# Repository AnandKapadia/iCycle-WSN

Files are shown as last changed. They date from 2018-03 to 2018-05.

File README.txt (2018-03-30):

README: 

This repository contains all of the files and documentation for the iCycle project. 

00_Documentation
01_Hardware 
	01_00_Reference
		Sparkfun library for the ATmega128RFA1_Dev (https://github.com/sparkfun/ATmega128RFA1_Dev)
	01_01_Library
	01_02_PCB
		v0.1 with arduinio mini, not finished, needs 4 layers
		v0.2 completed board with xbee, buzzer, leds
02_Software 
	01_00_Reference
		Sparkfun library for the ATmega128RFA1_Dev (https://github.com/sparkfun/ATmega128RFA1_Dev)

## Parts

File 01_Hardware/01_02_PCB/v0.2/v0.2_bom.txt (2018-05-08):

Partlist exported from /Users/akhome/Desktop/Year 4_2/18748/iCycle-WSN/01_Hardware/01_02_PCB/v0.2/v0.2.sch at 4/16/18 10:23 AM

Qty Value         Device               Package           Parts                                                                                 Description                                                                         PROD_ID     SF_SKU    VALUE     

1   16MHz         CRYSTAL5X3           CRYSTAL-SMD-5X3   MICROCONTROLLER1:Y1                                                                   Various standard crystals. Proven footprints. Spark Fun Electronics SKU : COM-00534                                 
1   32.768kHz     CRYSTAL32-SMD        CRYSTAL-32KHZ-SMD MICROCONTROLLER1:Y2                                                                   Various standard crystals. Proven footprints. Spark Fun Electronics SKU : COM-00534

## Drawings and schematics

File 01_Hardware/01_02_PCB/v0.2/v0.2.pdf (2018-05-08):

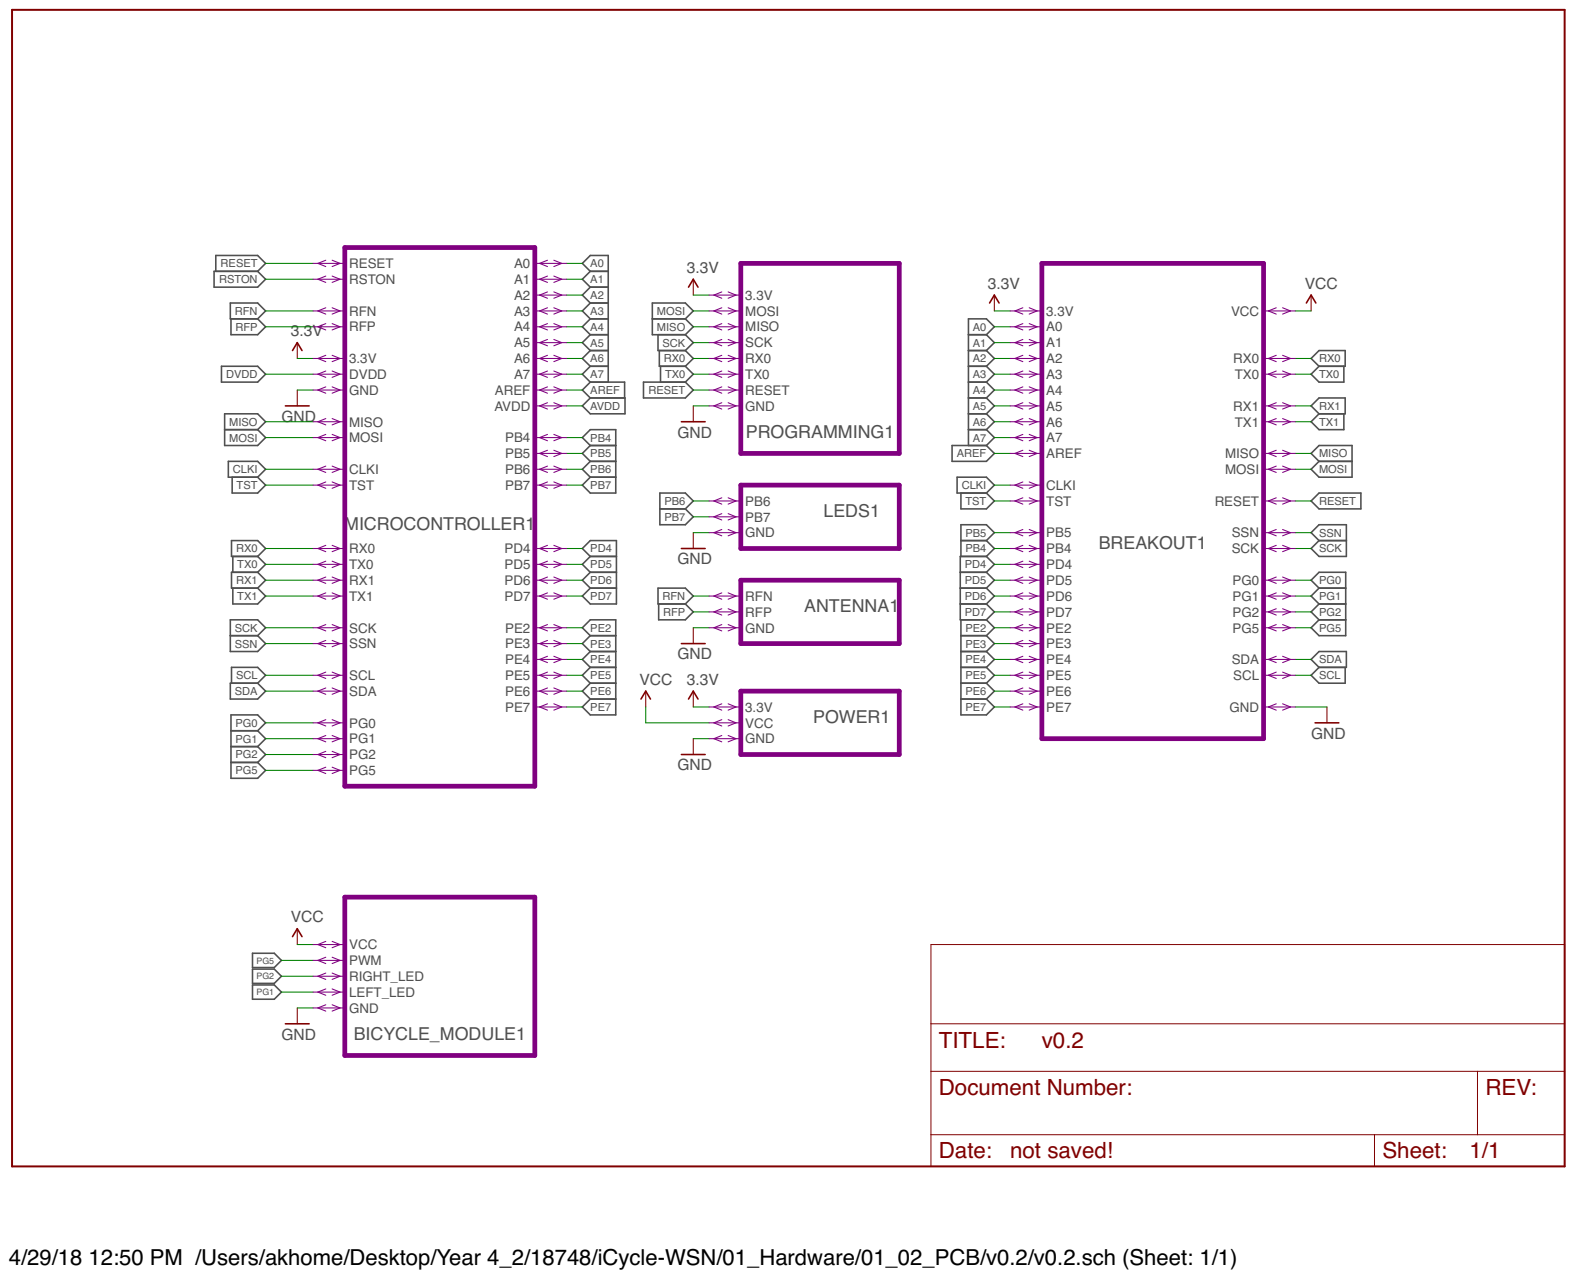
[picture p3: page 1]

RESET RFN
RSTON
RFP DVDD GND
3.3V MISO MOSI CLKI TST RX0 TX0 RX1 TX1 SCK

RESET SCK MISO MOSI RX0

Document Number: | REV:

Date: not saved! | Sheet: 1/1

4/29/18 12:50 PM /Users/akhome/Desktop/Year 4_2/18748/iCycle-WSN/01_Hardware/01_02_PCB/v0.2/v0.2.sch (Sheet: 1/1)

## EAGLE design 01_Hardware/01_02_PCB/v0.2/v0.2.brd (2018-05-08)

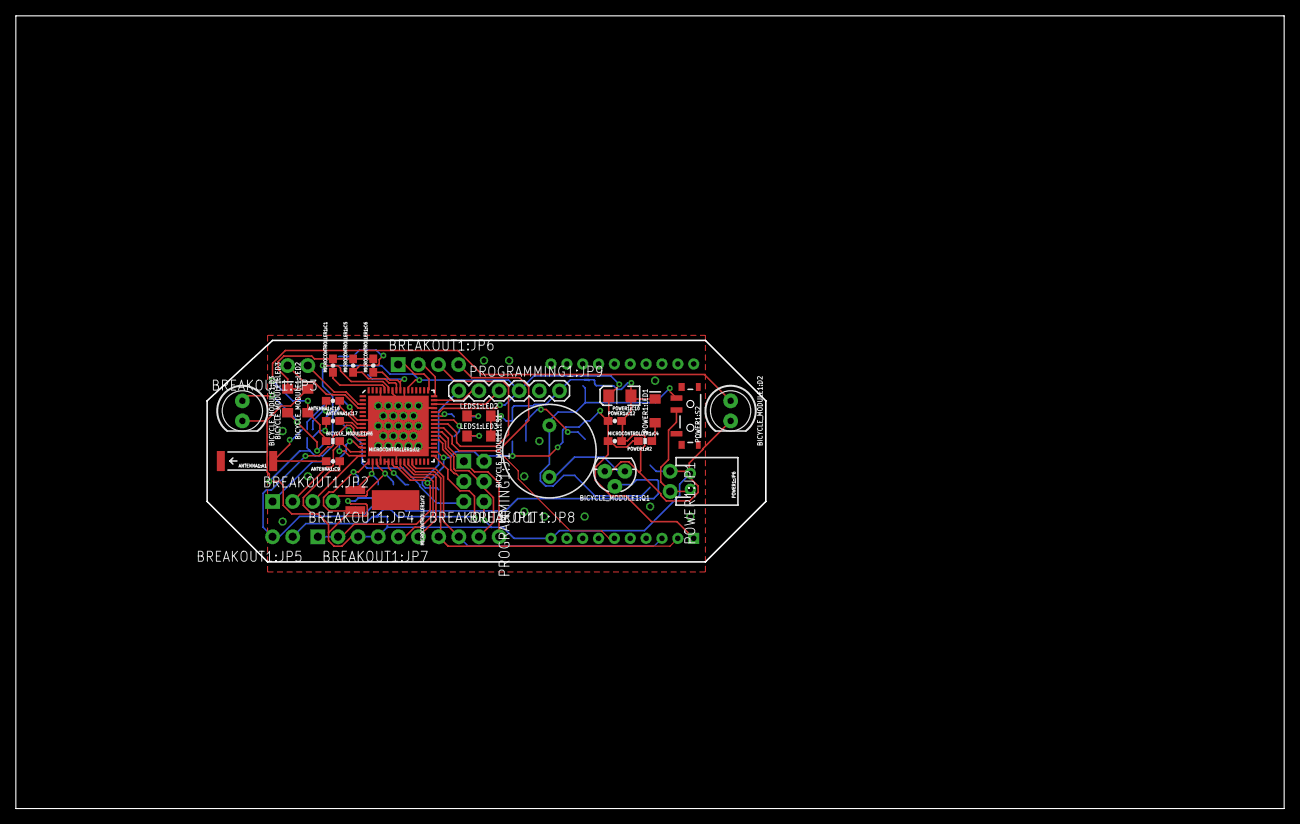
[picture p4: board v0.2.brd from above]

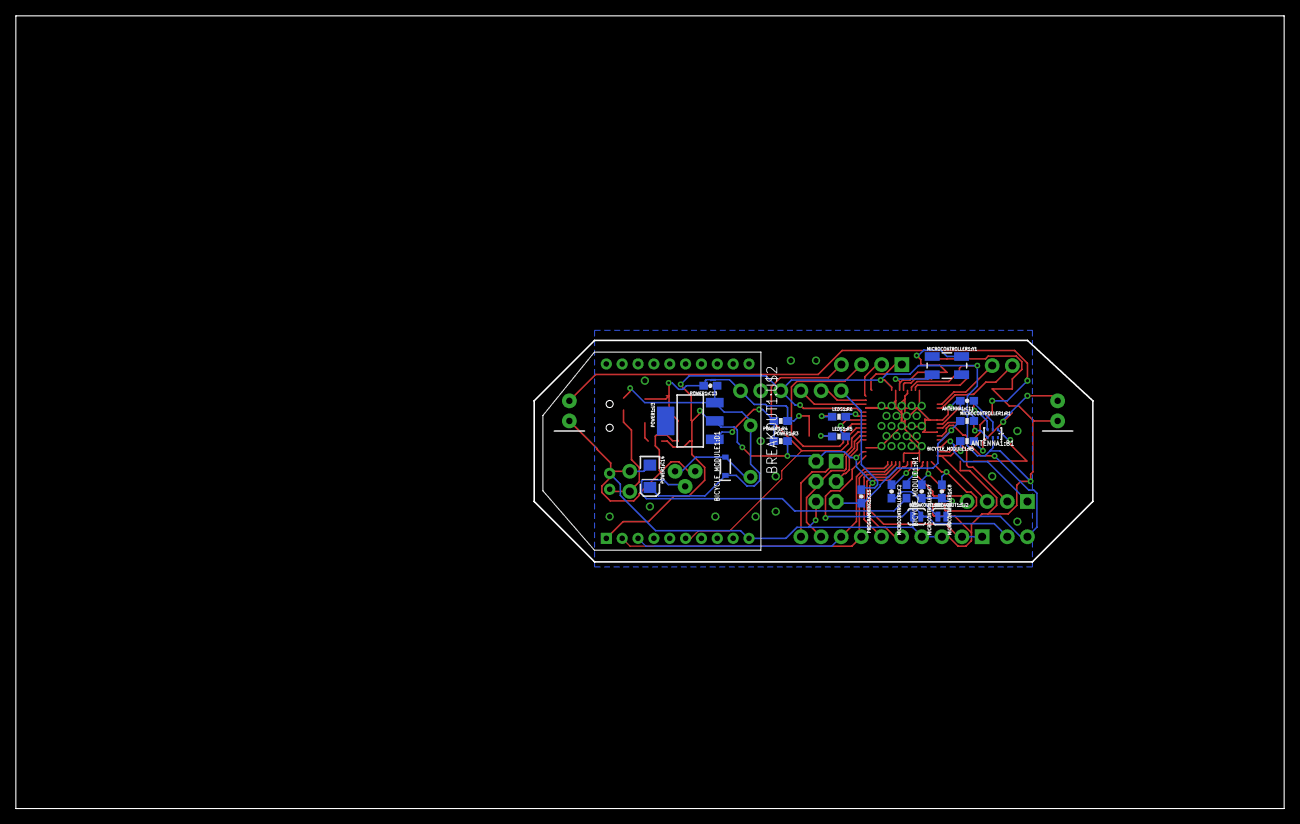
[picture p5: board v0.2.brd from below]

Board: 2 copper layers, 160.0 x 100.0 mm, 57 parts (21 on the bottom side), 49 nets.

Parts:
ANTENNA1:A1: ANTENNA2SMD5; ANTENNA-CHIP5
ANTENNA1:B1: 748421245; BALUN-0805
ANTENNA1:C9: 0.75pF; 0603-CAP
ANTENNA1:C11: 22pF; 0603-CAP
ANTENNA1:C16, ANTENNA1:C17: JUMP; 0603-CAP
BICYCLE_MODULE1:D1: 250mA/100V; SOD-323
BICYCLE_MODULE1:D2, BICYCLE_MODULE1:D3: LED_5MM
BICYCLE_MODULE1:LED2, BICYCLE_MODULE1:LED3: GREEN; LED-1206
BICYCLE_MODULE1:LS1: BUZZER-PTH; BUZZER-12MM
BICYCLE_MODULE1:Q1: 600mA/40V; TO-92
BICYCLE_MODULE1:R1: 180; 0603
BICYCLE_MODULE1:R5, BICYCLE_MODULE1:R6: 330; 0603-RES
BREAKOUT1:JP1, BREAKOUT1:JP3, BREAKOUT1:JP5, BREAKOUT1:JP7, BREAKOUT1:JP8: 1X02_NO_SILK
BREAKOUT1:JP2, BREAKOUT1:JP4, BREAKOUT1:JP6: 1X04_NO_SILK
BREAKOUT1:SJ1, BREAKOUT1:SJ2: SJ_2S-TRACE
BREAKOUT1:U$2: XBEE
LEDS1:LED2, LEDS1:LED3: GREEN; LED-1206
LEDS1:R5, LEDS1:R6: 330; 0603-RES
MICROCONTROLLER1:C1, MICROCONTROLLER1:C2, MICROCONTROLLER1:C4: 1uF; 0603-CAP
MICROCONTROLLER1:C5, MICROCONTROLLER1:C6, MICROCONTROLLER1:C7, MICROCONTROLLER1:C8: 12pF; 0603-CAP
MICROCONTROLLER1:R1: 10k; 0603-RES
MICROCONTROLLER1:U2: ATMEGA128RFA1; QFN-64
MICROCONTROLLER1:Y1: 16MHz; CRYSTAL-SMD-5X3
MICROCONTROLLER1:Y2: 32.768kHz; CRYSTAL-32KHZ-SMD
POWER1:C10, POWER1:C14: 10uF; EIA3216
POWER1:C12: 1uF; 0603-CAP
POWER1:C13: 0.1uF; 0603-CAP
POWER1:JP1: 1X02_NO_SILK
POWER1:JP6: JST-2-PTH
POWER1:LED1: RED; LED-1206
POWER1:R2: 1k; 0603-RES
POWER1:R3: 240; 0603-RES
POWER1:R4: 390; 0603-RES
POWER1:S2: SWITCH-SPST-SMD-A
POWER1:U3: LM1117; SOT223
PROGRAMMING1:C15: 0.1uF; 0603-CAP
PROGRAMMING1:J1: ISP; 2X3-NS
PROGRAMMING1:JP9: FTDI; FTDI_BASIC

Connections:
3.3V: BREAKOUT1:JP4.1, BREAKOUT1:JP4.2, BREAKOUT1:U$2.1, MICROCONTROLLER1:C4.1, MICROCONTROLLER1:R1.2, MICROCONTROLLER1:U2.23, MICROCONTROLLER1:U2.34, MICROCONTROLLER1:U2.44, MICROCONTROLLER1:U2.54, MICROCONTROLLER1:U2.59, POWER1:C10.A, POWER1:C12.1, POWER1:R2.2, POWER1:R3.2, POWER1:U3.2, PROGRAMMING1:J1.2, PROGRAMMING1:JP9.VCC
A4: BREAKOUT1:JP3.1, MICROCONTROLLER1:U2.3
A5: BREAKOUT1:JP3.2, MICROCONTROLLER1:U2.4
ANTENNA1:N$62: ANTENNA1:B1.2, ANTENNA1:C11.1
ANTENNA1:N$63: ANTENNA1:B1.3, ANTENNA1:C16.2
ANTENNA1:N$64: ANTENNA1:B1.4, ANTENNA1:C17.1
ANTENNA1:RFANT: ANTENNA1:A1.FEED, ANTENNA1:B1.1, ANTENNA1:C9.2
AVDD: MICROCONTROLLER1:C1.1, MICROCONTROLLER1:U2.60
BICYCLE_MODULE1:N$1: BICYCLE_MODULE1:Q1.2, BICYCLE_MODULE1:R1.2
BICYCLE_MODULE1:N$2: BICYCLE_MODULE1:D1.A, BICYCLE_MODULE1:LS1.-, BICYCLE_MODULE1:Q1.1
BICYCLE_MODULE1:N$65: BICYCLE_MODULE1:D3.A, BICYCLE_MODULE1:LED3.A, BICYCLE_MODULE1:R5.1
BICYCLE_MODULE1:N$66: BICYCLE_MODULE1:D2.A, BICYCLE_MODULE1:LED2.A, BICYCLE_MODULE1:R6.1
CLKI: BREAKOUT1:JP5.1, BREAKOUT1:SJ1.2, MICROCONTROLLER1:U2.33
DVDD: MICROCONTROLLER1:C2.1, MICROCONTROLLER1:U2.21, MICROCONTROLLER1:U2.22
GND: ANTENNA1:B1.5, ANTENNA1:C9.1, ANTENNA1:C11.2, BICYCLE_MODULE1:D2.K, BICYCLE_MODULE1:D3.K, BICYCLE_MODULE1:LED2.C, BICYCLE_MODULE1:LED3.C, BICYCLE_MODULE1:Q1.3, BREAKOUT1:JP4.3, BREAKOUT1:JP4.4, BREAKOUT1:SJ1.1, BREAKOUT1:SJ2.1, BREAKOUT1:U$2.10, LEDS1:LED2.C, LEDS1:LED3.C, MICROCONTROLLER1:C1.2, MICROCONTROLLER1:C2.2, MICROCONTROLLER1:C4.2, MICROCONTROLLER1:C5.2, MICROCONTROLLER1:C6.2, MICROCONTROLLER1:C7.2, MICROCONTROLLER1:C8.2, MICROCONTROLLER1:U2.7, MICROCONTROLLER1:U2.10, MICROCONTROLLER1:U2.20, MICROCONTROLLER1:U2.24, MICROCONTROLLER1:U2.35, MICROCONTROLLER1:U2.45, MICROCONTROLLER1:U2.55, MICROCONTROLLER1:U2.58, MICROCONTROLLER1:U2.61, MICROCONTROLLER1:U2.65, POWER1:C10.C, POWER1:C12.2, POWER1:C13.2, POWER1:C14.C, POWER1:JP1.1, POWER1:JP6.1, POWER1:LED1.C, POWER1:R4.1, PROGRAMMING1:J1.6, PROGRAMMING1:JP9.GND
LEDS1:N$65: LEDS1:LED3.A, LEDS1:R5.1
LEDS1:N$66: LEDS1:LED2.A, LEDS1:R6.1
MICROCONTROLLER1:N$57: MICROCONTROLLER1:C5.1, MICROCONTROLLER1:U2.57, MICROCONTROLLER1:Y1.3
MICROCONTROLLER1:N$58: MICROCONTROLLER1:C6.1, MICROCONTROLLER1:U2.56, MICROCONTROLLER1:Y1.1
MICROCONTROLLER1:N$59: MICROCONTROLLER1:C7.1, MICROCONTROLLER1:U2.18, MICROCONTROLLER1:Y2.X1
MICROCONTROLLER1:N$60: MICROCONTROLLER1:C8.1, MICROCONTROLLER1:U2.17, MICROCONTROLLER1:Y2.X2
MISO: BREAKOUT1:JP8.2, MICROCONTROLLER1:U2.39, PROGRAMMING1:J1.1
MOSI: BREAKOUT1:JP8.1, MICROCONTROLLER1:U2.38, PROGRAMMING1:J1.4
PB4: BREAKOUT1:JP6.4, BREAKOUT1:U$2.6, MICROCONTROLLER1:U2.40
PB5: BREAKOUT1:JP6.3, MICROCONTROLLER1:U2.41
PB6: LEDS1:R5.2, MICROCONTROLLER1:U2.42
PB7: LEDS1:R6.2, MICROCONTROLLER1:U2.43
PE2: BREAKOUT1:JP6.2, MICROCONTROLLER1:U2.48
PE3: BREAKOUT1:JP6.1, MICROCONTROLLER1:U2.49
PG0: BREAKOUT1:JP2.1, MICROCONTROLLER1:U2.14
PG1: BICYCLE_MODULE1:R6.2, BREAKOUT1:JP2.2, MICROCONTROLLER1:U2.15
PG2: BICYCLE_MODULE1:R5.2, BREAKOUT1:JP2.3, MICROCONTROLLER1:U2.16
PG5: BICYCLE_MODULE1:R1.1, BREAKOUT1:JP2.4, MICROCONTROLLER1:U2.19
POWER1:FB: POWER1:R3.1, POWER1:R4.2, POWER1:U3.1
POWER1:N$61: POWER1:LED1.A, POWER1:R2.1
POWER1:N$67: POWER1:JP1.2, POWER1:JP6.2, POWER1:S2.2
PROGRAMMING1:DTR: PROGRAMMING1:C15.1, PROGRAMMING1:JP9.DTR
RESET: MICROCONTROLLER1:R1.1, MICROCONTROLLER1:U2.12, PROGRAMMING1:C15.2, PROGRAMMING1:J1.5
RFN: ANTENNA1:C17.2, MICROCONTROLLER1:U2.9
RFP: ANTENNA1:C16.1, MICROCONTROLLER1:U2.8
RX0: MICROCONTROLLER1:U2.46, PROGRAMMING1:JP9.TXO
RX1: BREAKOUT1:JP1.1, BREAKOUT1:U$2.2, MICROCONTROLLER1:U2.27
SCK: MICROCONTROLLER1:U2.37, PROGRAMMING1:J1.3
SCL: BREAKOUT1:JP7.2, MICROCONTROLLER1:U2.25
SDA: BREAKOUT1:JP7.1, MICROCONTROLLER1:U2.26
TST: BREAKOUT1:JP5.2, BREAKOUT1:SJ2.2, MICROCONTROLLER1:U2.11
TX0: MICROCONTROLLER1:U2.47, PROGRAMMING1:JP9.RXI
TX1: BREAKOUT1:JP1.2, BREAKOUT1:U$2.3, MICROCONTROLLER1:U2.28
VCC: BICYCLE_MODULE1:D1.C, BICYCLE_MODULE1:LS1.+, POWER1:C13.1, POWER1:C14.A, POWER1:S2.1, POWER1:U3.3

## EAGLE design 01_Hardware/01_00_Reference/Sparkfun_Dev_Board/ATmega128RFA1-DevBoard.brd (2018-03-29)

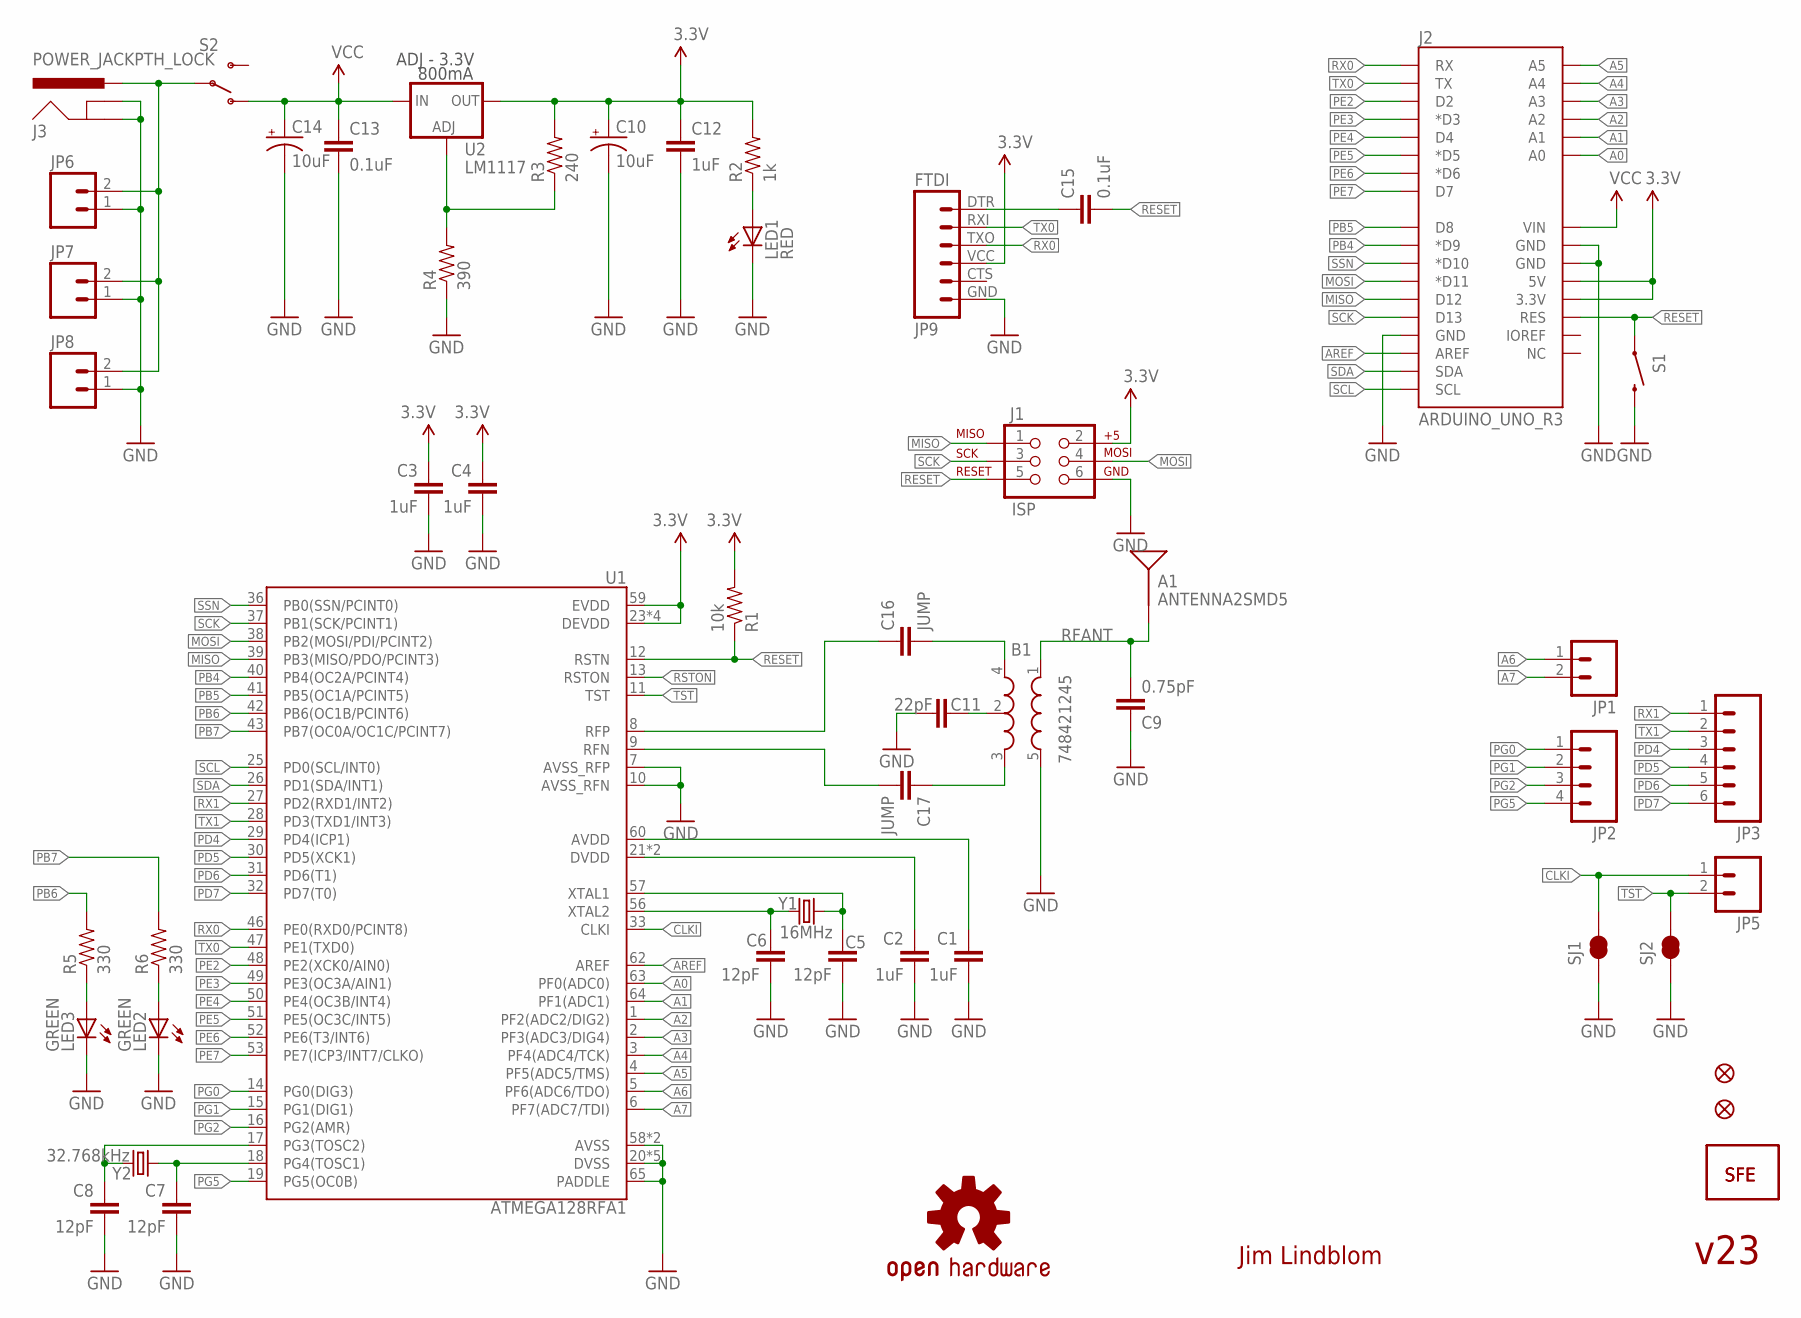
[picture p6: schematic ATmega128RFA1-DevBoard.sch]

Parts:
A1: ANTENNA2SMD5; ANTENNA-CHIP5
B1: 748421245; BALUN
C1, C2, C3, C4, C12: 1uF; 0402-CAP
C5, C6, C7, C8: 12pF; 0402-CAP
C9: 0.75pF; 0402-CAP
C10, C14: 10uF; EIA3216
C11: 22pF; 0402-CAP
C13, C15: 0.1uF; 0402-CAP
C16, C17: JUMP; 0402-CAP
FID1, FID2: FIDUCIALUFIDUCIAL; MICRO-FIDUCIAL
J1: ISP; 2X3-NS
J2: ARDUINO_UNO_R3
J3: POWER_JACKPTH_LOCK; POWER_JACK_PTH_LOCK
JP1, JP5, JP7: M021X02_NO_SILK; 1X02_NO_SILK
JP2: M041X04_NO_SILK; 1X04_NO_SILK
JP3: M06SIP-NS; 1X06_NS
JP4, JP10: LOGO-SFENEW; SFE-NEW-WEBLOGO
JP6: M02JST-PTH-2; JST-2-PTH
JP8: M023.5MM-NO_SILK; SCREWTERMINAL-3.5MM-2-NS
JP9: FTDI; FTDI_BASIC
LED1: RED; LED-0603
LED2, LED3: GREEN; LED-0603
R1: 10k; 0402-RES
R2: 1k; 0402-RES
R3: 240; 0402-RES
R4: 390; 0402-RES
R5, R6: 330; 0402-RES
S1: SWITCH-MOMENTARY-2SMD; TACTILE_SWITCH_SMD
S2: SWITCH-SPST-SMD-A
SJ1, SJ2: SOLDERJUMPERTRACE; SJ_2S-TRACE
U1: ATMEGA128RFA1; QFN-64
U2: LM1117; SOT223
U$1: OSHW-LOGOS; OSHW-LOGO-S
Y1: 16MHz; CRYSTAL-SMD-5X3
Y2: 32.768kHz; CRYSTAL-32KHZ-SMD

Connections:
3.3V: C3.1, C4.1, C10.A (+), C12.1, J1.2, J2.3.3V, J2.5V, JP9.VCC (4), R1.2, R2.2, R3.2, U1.23 (DEVDD), U1.34 (DEVDD), U1.44 (DEVDD), U1.54 (DEVDD), U1.59 (EVDD), U2.2 (OUT)
A0: J2.A0, U1.63 (PF0(ADC0))
A1: J2.A1, U1.64 (PF1(ADC1))
A2: J2.A2, U1.1 (PF2(ADC2/DIG2))
A3: J2.A3, U1.2 (PF3(ADC3/DIG4))
A4: J2.A4, U1.3 (PF4(ADC4/TCK))
A5: J2.A5, U1.4 (PF5(ADC5/TMS))
A6: JP1.1, U1.5 (PF6(ADC6/TDO))
A7: JP1.2, U1.6 (PF7(ADC7/TDI))
AREF: J2.AREF, U1.62 (AREF)
AVDD: C1.1, U1.60 (AVDD)
CLKI: JP5.1, SJ1.2, U1.33 (CLKI)
DTR: C15.1, JP9.DTR (1)
DVDD: C2.1, U1.21 (DVDD), U1.22 (DVDD)
FB: R3.1, R4.2, U2.1 (ADJ)
GND: B1.5 (GND), C1.2, C2.2, C3.2, C4.2, C5.2, C6.2, C7.2, C8.2, C9.1, C10.C (-), C11.2, C12.2, C13.2, C14.C (-), J1.6, J2.GND@0 (GND), J2.GND@1 (GND), J2.GND@2 (GND), J3.GND, J3.GNDBREAK, JP6.1, JP7.1, JP8.1, JP9.GND (6), LED1.C, LED2.C, LED3.C, R4.1, S1.3 (2), SJ1.1, SJ2.1, U1.7 (AVSS_RFP), U1.10 (AVSS_RFN), U1.20 (DVSS), U1.24 (DVSS), U1.35 (DVSS), U1.45 (DVSS), U1.55 (DVSS), U1.58 (AVSS), U1.61 (AVSS), U1.65 (PADDLE)
MISO: J1.1, J2.D12, U1.39 (PB3(MISO/PDO/PCINT3))
MOSI: J1.4, J2.D11 (*D11), U1.38 (PB2(MOSI/PDI/PCINT2))
unnamed: LED1.A, R2.1
unnamed: C5.1, U1.57 (XTAL1), Y1.3 (2)
unnamed: C6.1, U1.56 (XTAL2), Y1.1
unnamed: C7.1, U1.18 (PG4(TOSC1)), Y2.X1 (1)
unnamed: C8.1, U1.17 (PG3(TOSC2)), Y2.X2 (2)
unnamed: B1.2 (GND), C11.1
unnamed: LED3.A, R5.1
unnamed: J3.PWR, JP6.2, JP7.2, JP8.2, S2.2
unnamed: B1.4 (OUT1), C16.2
unnamed: B1.3 (OUT2), C17.1
unnamed: LED2.A, R6.1
PB4: J2.D9 (*D9), U1.40 (PB4(OC2A/PCINT4))
PB5: J2.D8, U1.41 (PB5(OC1A/PCINT5))
PB6: R5.2, U1.42 (PB6(OC1B/PCINT6))
PB7: R6.2, U1.43 (PB7(OC0A/OC1C/PCINT7))
PD4: JP3.3, U1.29 (PD4(ICP1))
PD5: JP3.4, U1.30 (PD5(XCK1))
PD6: JP3.5, U1.31 (PD6(T1))
PD7: JP3.6, U1.32 (PD7(T0))
PE2: J2.D2, U1.48 (PE2(XCK0/AIN0))
PE3: J2.D3 (*D3), U1.49 (PE3(OC3A/AIN1))
PE4: J2.D4, U1.50 (PE4(OC3B/INT4))
PE5: J2.D5 (*D5), U1.51 (PE5(OC3C/INT5))
PE6: J2.D6 (*D6), U1.52 (PE6(T3/INT6))
PE7: J2.D7, U1.53 (PE7(ICP3/INT7/CLKO))
PG0: JP2.1, U1.14 (PG0(DIG3))
PG1: JP2.2, U1.15 (PG1(DIG1))
PG2: JP2.3, U1.16 (PG2(AMR))
PG5: JP2.4, U1.19 (PG5(OC0B))
RESET: C15.2, J1.5, J2.RES, R1.1, S1.1, U1.12 (RSTN)
RFANT: A1.FEED, B1.1 (IN), C9.2
RFN: C17.2, U1.9 (RFN)
RFP: C16.1, U1.8 (RFP)
RSTON: U1.13 (RSTON)
RX0: J2.RX, JP9.TXO (3), U1.46 (PE0(RXD0/PCINT8))
RX1: JP3.1, U1.27 (PD2(RXD1/INT2))
SCK: J1.3, J2.D13, U1.37 (PB1(SCK/PCINT1))
SCL: J2.SCL, U1.25 (PD0(SCL/INT0))
SDA: J2.SDA, U1.26 (PD1(SDA/INT1))
SSN: J2.D10 (*D10), U1.36 (PB0(SSN/PCINT0))
TST: JP5.2, SJ2.2, U1.11 (TST)
TX0: J2.TX, JP9.RXI (2), U1.47 (PE1(TXD0))
TX1: JP3.2, U1.28 (PD3(TXD1/INT3))
VCC: C13.1, C14.A (+), J2.VIN, S2.1 (O), U2.3 (IN)

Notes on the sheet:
Jim Lindblom
800mA
ADJ - 3.3V
v23

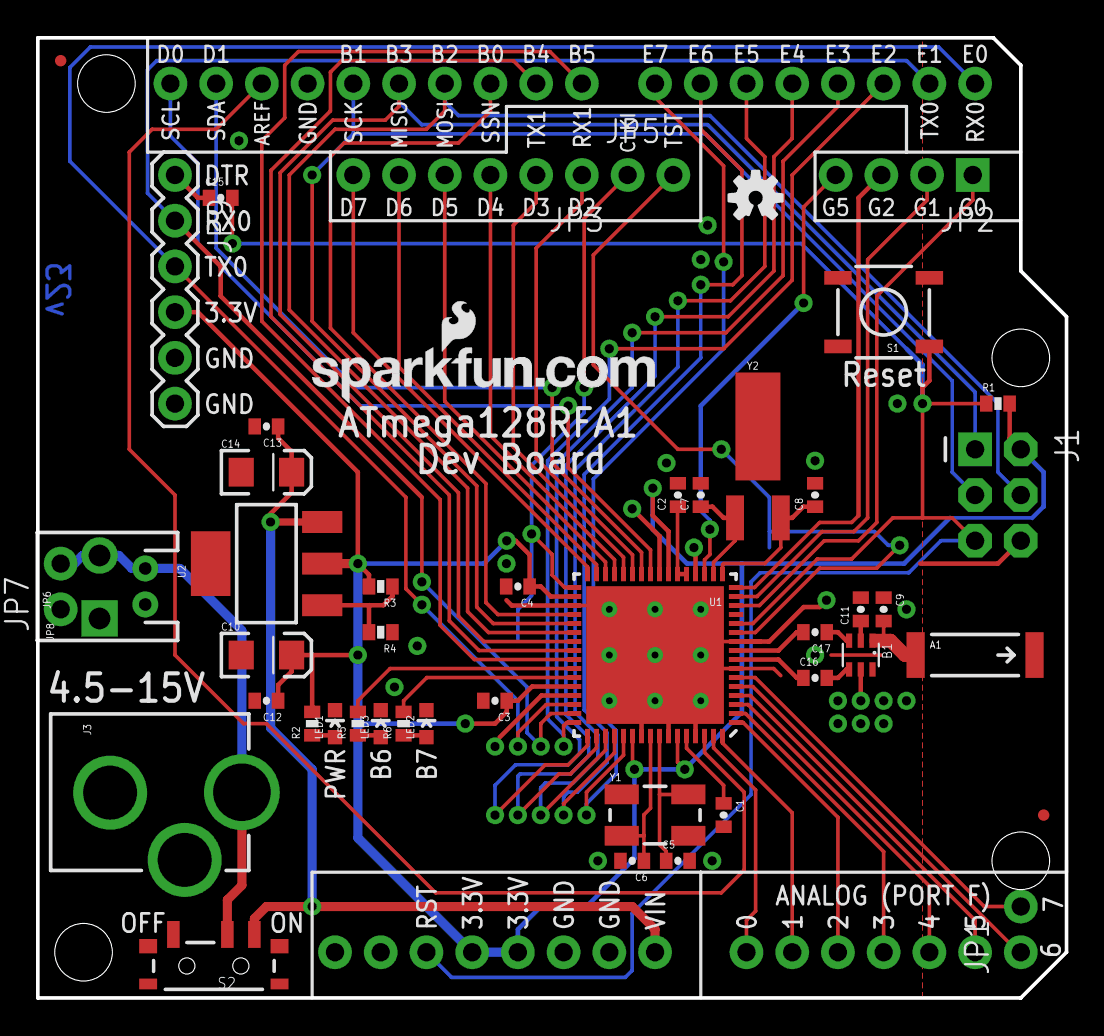
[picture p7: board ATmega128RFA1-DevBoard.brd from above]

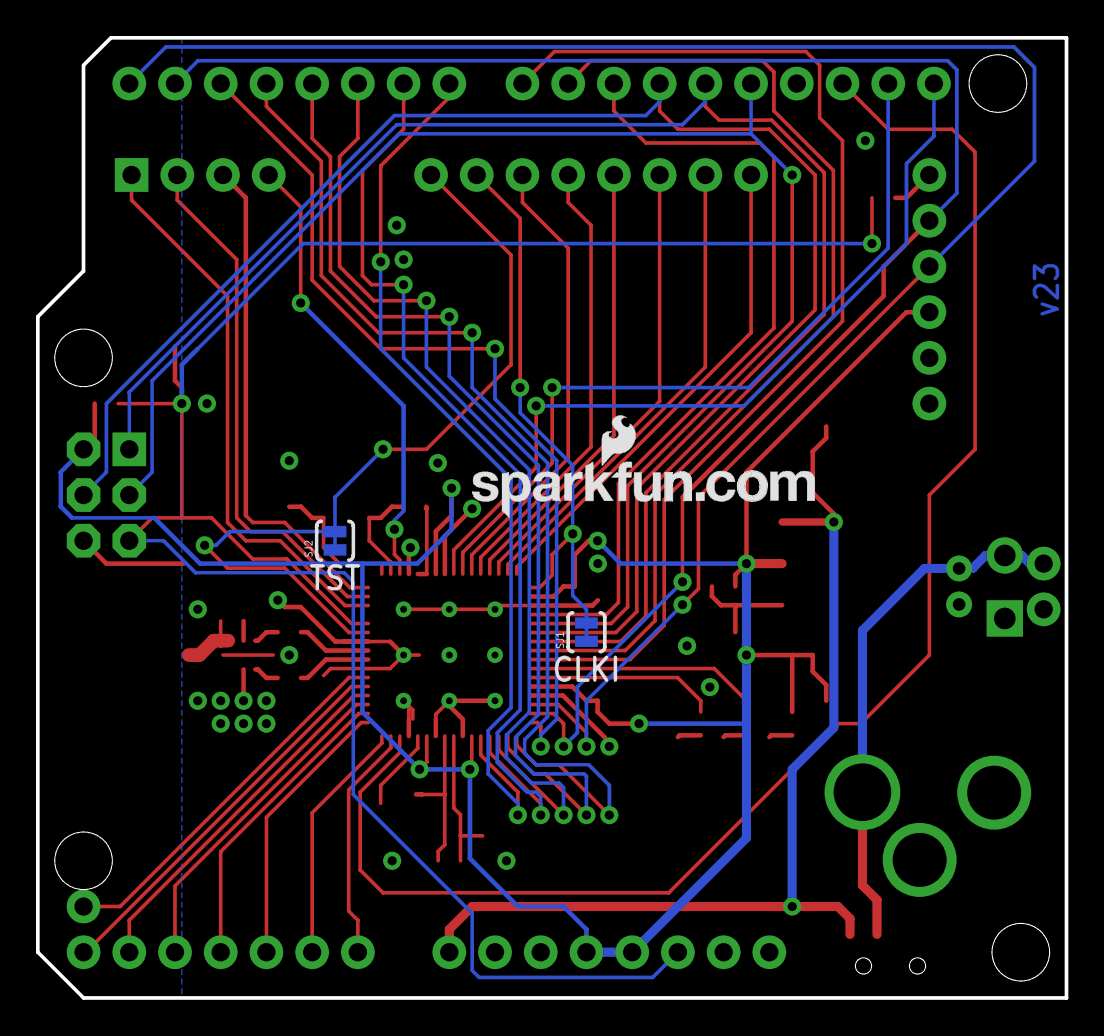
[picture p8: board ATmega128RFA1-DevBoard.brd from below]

Board: 2 copper layers, 57.1 x 53.3 mm, 52 parts (3 on the bottom side), 61 nets.

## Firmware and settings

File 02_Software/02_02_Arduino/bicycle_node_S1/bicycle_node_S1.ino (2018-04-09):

/**
 * Copyright (c) 2009 Andrew Rapp. All rights reserved.
 *
 * This file is part of XBee-Arduino.
 *
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
 * You should have received a copy of the GNU General Public License
 * along with XBee-Arduino.  If not, see <http://www.gnu.org/licenses/>.
 */

#include <XBee.h>
#include <SparkFun_ADXL345.h>

#define XBEE_SUCCESS  0
#define XBEE_ERROR    0xff
#define XBEE_RX_EMPTY 1


#define BROADCAST_ADDRESS (0xFFFF)

// create the XBee object
XBee xbee = XBee();

// create the accelerometer object (i2c)
ADXL345 accelerometer = ADXL345();           


/*
// allocate two bytes for to hold a 10-bit analog reading
uint8_t payload[] = { 0, 0 };

// with Series 1 you can use either 16-bit or 64-bit addressing

// 16-bit addressing: Enter address of remote XBee, typically the coordinator
Tx16Request tx = Tx16Request(0xFFFF, payload, sizeof(payload));

// 64-bit addressing: This is the SH + SL address of remote XBee
//XBeeAddress64 addr64 = XBeeAddress64(0x0013a200, 0x4008b490);
// unless you have MY on the receiving radio set to FFFF, this will be received as a RX16 packet
//Tx64Request tx = Tx64Request(addr64, payload, sizeof(payload));

TxStatusResponse txStatus = TxStatusResponse();
*/
// IO Pinmap

const int leftLed = 2;
const int rightLed = 4;
const int txLed = 7;
const int statusLed = 8;
const int rxLed = 9;
const int buzzer = 10;
const int buttonPin = 12;
const int errorLed = 13;

static Rx16Response rx16 = Rx16Response();

typedef struct{
  int16_t x;
  int16_t y;
  int16_t z;
} accel_data_t;

typedef enum location_field_t {
  NORTH,
  NORTHEAST,
  EAST,
  SOUTHEAST,
  SOUTH,
  SOUTHWEST,
  WEST,
  NORTHWEST
} location_field_t;

void setup() {
  //start the serial port
  Serial.begin(9600);
  
  //setup the io
  pinMode(leftLed, OUTPUT);
  pinMode(rightLed, OUTPUT);
  pinMode(txLed, OUTPUT);
  pinMode(rxLed, OUTPUT);
  pinMode(statusLed, OUTPUT);
  pinMode(errorLed, OUTPUT);
  pinMode(buzzer, OUTPUT);
  pinMode(buttonPin, INPUT);

  //ensure all leds work
  flashLed(leftLed, 2, 250);
  flashLed(rightLed, 2, 250);
  flashLed(txLed, 2, 250);
  flashLed(rxLed, 2, 250);
  flashLed(statusLed, 2, 250);
  flashLed(errorLed, 2, 250);
  flashLed(buzzer, 2, 250);

  //accel setup
  setup_accelerometer();

  //xbee setup
  xbee.setSerial(Serial);
}


void loop() {  
  //inits
  uint8_t count = 0;
  static bool buzzer_bool = false;
  static uint16_t buzzer_count = 0;
  uint8_t buttonVal = digitalRead(buttonPin);
  uint8_t txPayload[1] = {0};
  accel_data_t accel_data;
  accel_data.x = 0;
  accel_data.y = 0;
  accel_data.z = 0;

  //send if button pushed
  if(buttonVal) {
    while(buttonVal) {
      count++;
      buttonVal = digitalRead(buttonPin);
      delay(100);
    }

    //get the accelerometer data
    accelerometer.readAccel(&(accel_data.x), &(accel_data.y), &(accel_data.z)); 
    Serial.print(accel_data.x);
    Serial.print(", ");
    Serial.print(accel_data.y);
    Serial.print(", ");
    Serial.println(accel_data.z); 
    sendPacket(BROADCAST_ADDRESS, (uint8_t *)&accel_data, sizeof(accel_data_t));
    flashLed(statusLed, count, 50);
    delay(1000);
  }

  if(buzzer_bool){
    buzzer_count++;
  }
  else{
    buzzer_count = 0;
  }
  if(buzzer_count > 1000){
    buzzer_count = 0;
    buzzer_bool = false; 
    digitalWrite(buzzer, LOW);
    delay(1);
  }
  uint8_t retv;
  retv = retrievePacket();
  if(retv  == XBEE_ERROR) {
    flashLed(errorLed, 2, 100);
  } else if(retv == XBEE_SUCCESS){
    
    flashLed(rxLed, 2, 100);
    uint8_t *rxPayload = rx16.getData();
    uint8_t *rxFrame = rx16.getFrameData();
    uint16_t sourceAddr;
    location_field_t location;
    sourceAddr = (((uint16_t) rxFrame[0]) << 8) | ((uint16_t) rxFrame[1]);//*(uint16_t*)rxFrame;
    if(sourceAddr == 0){
      location = rxPayload[0];
      switch(location){
        case SOUTH: 
          digitalWrite(leftLed, LOW);
          digitalWrite(rightLed, LOW);
          digitalWrite(buzzer, LOW);
          buzzer_bool = false;
          delay(1);
          break;
        case NORTHEAST:
          digitalWrite(buzzer, HIGH);
          digitalWrite(rightLed, HIGH);
          digitalWrite(leftLed, LOW);
          buzzer_bool = true;
          break;
        case SOUTHEAST: 
        case EAST: 
          digitalWrite(rightLed, HIGH);
          digitalWrite(leftLed, LOW);          
          digitalWrite(buzzer, LOW);
          buzzer_bool = false;
          break;
        case NORTHWEST:
          digitalWrite(buzzer, HIGH);
          digitalWrite(rightLed, LOW);
          digitalWrite(leftLed, HIGH);
          buzzer_bool = true;
          break;
        case SOUTHWEST: 
        case WEST: 
          digitalWrite(rightLed, LOW);
          digitalWrite(leftLed, HIGH);          
          digitalWrite(buzzer, LOW);
          buzzer_bool = false;
          break;
        case NORTH:
          digitalWrite(leftLed, LOW);
          digitalWrite(rightLed, LOW);
          digitalWrite(buzzer, HIGH);
          buzzer_bool = true;
          break;
        default: 
          break;
      }
      delay(1);
    }
  }

 
  delay(1);
}


// Helper for sending an XBee Packet
// TODO add condition codes
void sendPacket(uint16_t destAddress, uint8_t* payload, uint8_t payloadSize) {

  // Setup the packet to send to the master node, typically the coordinator
  Tx16Request tx = Tx16Request(destAddress, payload, payloadSize);
  // Packet to hold the reponse from XBee after transmission complete
  TxStatusResponse txStatus = TxStatusResponse();

  xbee.send(tx);

  // flash TX indicator
  flashLed(txLed, 1, 100);
  
  // after sending a tx request, we expect a status response
  // wait up to 5 seconds for the status response
  if (xbee.readPacket(5000)) {
    // got a response!

    // should be a znet tx status              
    if (xbee.getResponse().getApiId() == TX_STATUS_RESPONSE) {
      xbee.getResponse().getTxStatusResponse(txStatus);

      // get the delivery status, the fifth byte
      if (txStatus.getStatus() == SUCCESS) {
        // success.  time to celebrate
        flashLed(txLed, 2, 250);
      } else {
        // the remote XBee did not receive our packet. is it powered on?
        flashLed(errorLed, 3, 250);
      }
    }      
  } else if (xbee.getResponse().isError()) {
    //nss.print("Error reading packet.  Error code: ");  
    //nss.println(xbee.getResponse().getErrorCode());
    // or flash error led
  } else {
    // local XBee did not provide a timely TX Status Response.  Radio is not configured properly or connected
    flashLed(errorLed, 2, 250);
  }
}




//Retrieve a received packet and store it in rx16
uint8_t retrievePacket(){
  xbee.readPacket();
    
  if (xbee.getResponse().isAvailable()) {
    // got something
    if (xbee.getResponse().getApiId() == RX_16_RESPONSE) {
      // got a rx packet
      xbee.getResponse().getRx64Response(rx16);
      return XBEE_SUCCESS;
    } else {
      // not something we were expecting
      return XBEE_ERROR;    
    }
  } else if (xbee.getResponse().isError()) {
    return XBEE_ERROR;
  } else {
    return XBEE_RX_EMPTY;
  }
}


static void flashLed(int pin, int times, int wait) {

  for (int i = 0; i < times; i++) {
    digitalWrite(pin, HIGH);
    delay(wait);
    digitalWrite(pin, LOW);

    if (i + 1 < times) {
      delay(wait);
    }
  }
}

static void setup_accelerometer(){
  accelerometer.powerOn();                     // Power on the accelerometer345

  accelerometer.setRangeSetting(16);           // Give the range settings
                                               // Accepted values are 2g, 4g, 8g or 16g
                                               // Higher Values = Wider Measurement Range
                                               // Lower Values = Greater Sensitivity

  accelerometer.setSpiBit(0);                  // Configure the device to be in 4 wire SPI mode when set to '0' or 3 wire SPI mode when set to 1
                                               // Default: Set to 1
                                               // SPI pins on the ATMega328: 11, 12 and 13 as reference in SPI Library 
   
  accelerometer.setActivityXYZ(1, 0, 0);       // Set to activate movement detection in the axes "accelerometer.setActivityXYZ(X, Y, Z);" (1 == ON, 0 == OFF)
  accelerometer.setActivityThreshold(75);      // 62.5mg per increment   // Set activity   // Inactivity thresholds (0-255)
 
  accelerometer.setInactivityXYZ(1, 0, 0);     // Set to detect inactivity in all the axes "accelerometer.setInactivityXYZ(X, Y, Z);" (1 == ON, 0 == OFF)
  accelerometer.setInactivityThreshold(75);    // 62.5mg per increment   // Set inactivity // Inactivity thresholds (0-255)
  accelerometer.setTimeInactivity(10);         // How many seconds of no activity is inactive?

  accelerometer.setTapDetectionOnXYZ(0, 0, 1); // Detect taps in the directions turned ON "accelerometer.setTapDetectionOnX(X, Y, Z);" (1 == ON, 0 == OFF)
 
  // Set values for what is considered a TAP and what is a DOUBLE TAP (0-255)
  accelerometer.setTapThreshold(50);           // 62.5 mg per increment
  accelerometer.setTapDuration(15);            // 625 μs per increment
  accelerometer.setDoubleTapLatency(80);       // 1.25 ms per increment
  accelerometer.setDoubleTapWindow(200);       // 1.25 ms per increment
 
  // Set values for what is considered FREE FALL (0-255)
  accelerometer.setFreeFallThreshold(7);       // (5 - 9) recommended - 62.5mg per increment
  accelerometer.setFreeFallDuration(30);       // (20 - 70) recommended - 5ms per increment
 
  // Setting all interupts to take place on INT1 pin
  //accelerometer.setImportantInterruptMapping(1, 1, 1, 1, 1);     // Sets "accelerometer.setEveryInterruptMapping(single tap, double tap, free fall, activity, inactivity);" 
                                                                   // Accepts only 1 or 2 values for pins INT1 and INT2. This chooses the pin on the accelerometer345 to use for Interrupts.
                                                                   // This library may have a problem using INT2 pin. Default to INT1 pin.
  
  // Turn on Interrupts for each mode (1 == ON, 0 == OFF)
  accelerometer.InactivityINT(0);
  accelerometer.ActivityINT(0);
  accelerometer.FreeFallINT(0);
  accelerometer.doubleTapINT(0);
  accelerometer.singleTapINT(0);
}

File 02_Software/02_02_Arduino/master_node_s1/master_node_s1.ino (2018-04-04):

/**
 *
 *
 */
 
#include <XBee.h>

#define XBEE_SUCCESS  0
#define XBEE_ERROR    0xff
#define XBEE_RX_EMPTY 1

#define NUM_CORNERS 2
#define MASTER_ADDRESS 0
#define REAR_LEFT_ADDRESS 1
#define REAR_RIGHT_ADDRESS 2


// TODO Expand to master sotring a set of corner data for each in a list of bikes

// TODO add timestamp for checking data freshness
typedef struct cornerNode_t {
  uint8_t addr;
  uint8_t rssi;
} cornerNode_t;

cornerNode_t corners[NUM_CORNERS];

XBee xbee = XBee(); 

/*
 * Packet setup for reception from a bike node
 */

//XBeeResponse response = XBeeResponse();
// create reusable response objects for responses we expect to handle 
static Rx16Response rx16 = Rx16Response();
//ModemStatusResponse msr = ModemStatusResponse();


/*
 * Packet setup for transmission from this node to the master
 */


int txLed = 8;
int rxLed = 9;
int rearLeftCornerLed = 6;
int rearRightCornerLed = 7;
int rearLeftRxLed = 2;
int rearRightRxLed = 4;
int errorLed = 13;

/* 
 * Helper functions 
 */

void flashLed(int pin, int times, int wait) {
    
    for (int i = 0; i < times; i++) {
      digitalWrite(pin, HIGH);
      delay(wait);
      digitalWrite(pin, LOW);
      
      if (i + 1 < times) {
        delay(wait);
      }
    }
}

//Retrieve a received packet and store it in rx16
uint8_t retrievePacket(){
  xbee.readPacket();
    
  if (xbee.getResponse().isAvailable()) {
    // got something
    if (xbee.getResponse().getApiId() == RX_16_RESPONSE) {
      // got a rx packet
      xbee.getResponse().getRx16Response(rx16);
      return XBEE_SUCCESS;
    } else {
      // not something we were expecting
      return XBEE_ERROR;    
    }
  } else if (xbee.getResponse().isError()) {
    return XBEE_ERROR;
  } else {
    return XBEE_RX_EMPTY;
  }
}

// Helper for sending an XBee Packet
// TODO add condition codes
void sendPacket(uint16_t destAddress, uint8_t* payload, uint8_t payloadSize) {

  // Setup the packet to send to the master node, typically the coordinator
  Tx16Request tx = Tx16Request(destAddress, payload, payloadSize);
  // Packet to hold the reponse from XBee after transmission complete
  TxStatusResponse txStatus = TxStatusResponse();

  xbee.send(tx);

  // flash TX indicator
  flashLed(txLed, 1, 100);
  
  // after sending a tx request, we expect a status response
  // wait up to 5 seconds for the status response
  if (xbee.readPacket(5000)) {
    // got a response!

    // should be a znet tx status              
    if (xbee.getResponse().getApiId() == TX_STATUS_RESPONSE) {
      xbee.getResponse().getTxStatusResponse(txStatus);

      // get the delivery status, the fifth byte
      if (txStatus.getStatus() == SUCCESS) {
        // success.  time to celebrate
        flashLed(txLed, 1, 100);
      } else {
        // the remote XBee did not receive our packet. is it powered on?
        flashLed(errorLed, 3, 250);
      }
    }      
  } else if (xbee.getResponse().isError()) {
    //nss.print("Error reading packet.  Error code: ");  
    //nss.println(xbee.getResponse().getErrorCode());
    // or flash error led
  } else {
    // local XBee did not provide a timely TX Status Response.  Radio is not configured properly or connected
    flashLed(errorLed, 2, 250);
  }
}

bool storeCornerData(uint8_t addr, uint8_t data) {
  for(uint8_t i = 0; i < NUM_CORNERS; i++) {
    if(corners[i].addr == addr) {
      corners[i].rssi = data;
      return true;
    }
  }
  return false;
}

uint8_t getCornerData(uint8_t addr) {
  for(uint8_t i = 0; i < NUM_CORNERS; i++) {
    if(corners[i].addr == addr) {
      return corners[i].rssi;
    }
  }
  //Something went wrong
  return 0;
}
void setup() {
  pinMode(rxLed, OUTPUT);
  pinMode(txLed, OUTPUT);
  pinMode(rearLeftRxLed, OUTPUT);
  pinMode(rearRightRxLed, OUTPUT);
  pinMode(rearLeftCornerLed, OUTPUT);
  pinMode(rearRightCornerLed, OUTPUT);
  pinMode(errorLed, OUTPUT);

  // Mark Corners
  corners[0].addr = REAR_LEFT_ADDRESS;
  corners[1].addr = REAR_RIGHT_ADDRESS;
  
  // start serial
  
  Serial.begin(9600);
  xbee.begin(Serial);
  
  flashLed(txLed, 2, 250);
  flashLed(rxLed, 2, 250);
  flashLed(rearRightCornerLed, 2, 250);
  flashLed(rearRightRxLed, 2, 250);
  flashLed(rearLeftCornerLed, 2, 250);
  flashLed(rearLeftRxLed, 2, 250);
  delay(500);
}

// continuously reads packets, looking for ZB Receive or Modem Status
void loop() {
    
  uint8_t retv;
  retv = retrievePacket();
  if(retv  == XBEE_ERROR) {
    flashLed(errorLed, 2, 100);
  } else if(retv == XBEE_SUCCESS){
    

    // Received payload
    uint8_t *rxPayload = rx16.getData();
    uint8_t *rxFrame = rx16.getFrameData();
    uint16_t cornerAddr;
    uint8_t cornerRssi;

    // Fill in source address
    // TODO convert to 64bit addressing so all bikes are unique
    cornerAddr = (((uint16_t) rxFrame[0]) << 8) | ((uint16_t) rxFrame[1]);

    cornerRssi = rxPayload[2];

    // Invert RSSI as it's reported as negative decibels
    if(storeCornerData(cornerAddr, cornerRssi)) {
      if(cornerAddr == REAR_LEFT_ADDRESS) {
        flashLed(rearLeftRxLed, 2, 250);
      }
      if(cornerAddr == REAR_RIGHT_ADDRESS) {
        flashLed(rearRightRxLed, 2, 250);
      }
      
    }
    flashLed(rxLed, 2, 100);
  }
  //flashLed(rearLeftCornerLed, getCornerData(REAR_LEFT_ADDRESS), 50);
  //analogWrite(rearLeftCornerLed, getCornerData(REAR_LEFT_ADDRESS));
  //analogWrite(rearRightCornerLed, getCornerData(REAR_RIGHT_ADDRESS));
  
  if(getCornerData(REAR_LEFT_ADDRESS) < getCornerData(REAR_RIGHT_ADDRESS)) {
    digitalWrite(rearLeftCornerLed, HIGH);
    digitalWrite(rearRightCornerLed, LOW);
  } else {
    digitalWrite(rearLeftCornerLed, LOW);
    digitalWrite(rearRightCornerLed, HIGH);
  }
  
  delay(1);
}

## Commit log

2018-03-29 Init
    repo setup
    [ATmega128RFA1-DevBoard.brd, ATmega128RFA1-DevBoard.sch]
2018-03-29 eagle repo setup
    [ATmega128RFA1-DevBoard.brd, ATmega128RFA1-DevBoard.sch, schematic_0.1.sch]
2018-03-30 adding board v0.1, v0.2 to version control
    [ATmega128RFA1-DevBoard.sch, schematic_0.1.sch, v0.1.brd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]
2018-03-30 v0.2 updates (minor traces), readme updates
    [v0.2.brd]
2018-04-02 xbee library and basic arduino code
2018-04-04 Arduino XBee: Mid-demo nodes
    New Arduino project for each the bike, corner and master node using
    series 1 XBees in API mode. Bike sends a broadcast, two corners
    receive and send the RSSI from the broadcast to the master, along with
    the nodeID of the bike node. Plenty to clean up, but the master seems to
    be deciding the binary location of the bike fairly well based on the
    RSSI from the two corners.
2018-04-04 Correctly displays car on white background
    [main.cpp]
2018-04-05 added library for accelerometer
2018-04-05 added imu support in bicycle node
2018-04-05 Added xbee drivers for writing and receiving
2018-04-05 Master with buzzer debugging
    [master_node_s1.ino]
2018-04-09 Corner Node: added bike payload bytes for IMU data
2018-04-29 3v3 reg uptE
    [v0.2.brd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]
2018-04-30 Bike Mole: Initialize Project
    First cde for bike mole. Currenlty sends a message with four payload
    bytes at a fixed rate. Receives messages, but does not process them yet
    Corner with bike, and attempted to retransmit bike message to the
    master. Bike lights/buzzer and IMU yet to be implemented.
    [conf_clock.h]
2018-04-30 WIP: Moved xbee files to uart, created corner pthread
2018-05-01 Bike Mole: Added IO response on reception
    When the bike mole receives a packet from the master, it now reads its
    relative location and sets the appropriate LEDs for the vehicles
    location. A timer is started at the expiry of which the LEDs are turned
    off. Buzzer code is commented out as the buzzer is not yet attached to
    the hardware.
    [main.c, moleRF.c]
2018-05-01 Corner Mole: added RSSI printout upon reception of bike message
2018-05-01 Corner and Bike: increasing tx power and switching channel

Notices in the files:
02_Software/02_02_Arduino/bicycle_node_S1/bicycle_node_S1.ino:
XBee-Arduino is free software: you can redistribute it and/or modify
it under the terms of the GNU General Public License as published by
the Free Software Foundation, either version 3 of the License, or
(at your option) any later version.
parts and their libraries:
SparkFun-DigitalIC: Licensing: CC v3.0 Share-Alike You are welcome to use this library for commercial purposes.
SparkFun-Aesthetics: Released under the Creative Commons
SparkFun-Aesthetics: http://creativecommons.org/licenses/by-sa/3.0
